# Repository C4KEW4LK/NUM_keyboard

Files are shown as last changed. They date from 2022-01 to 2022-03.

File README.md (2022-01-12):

# NUM_keyboard
Custom numpad to match CTRL keyboard

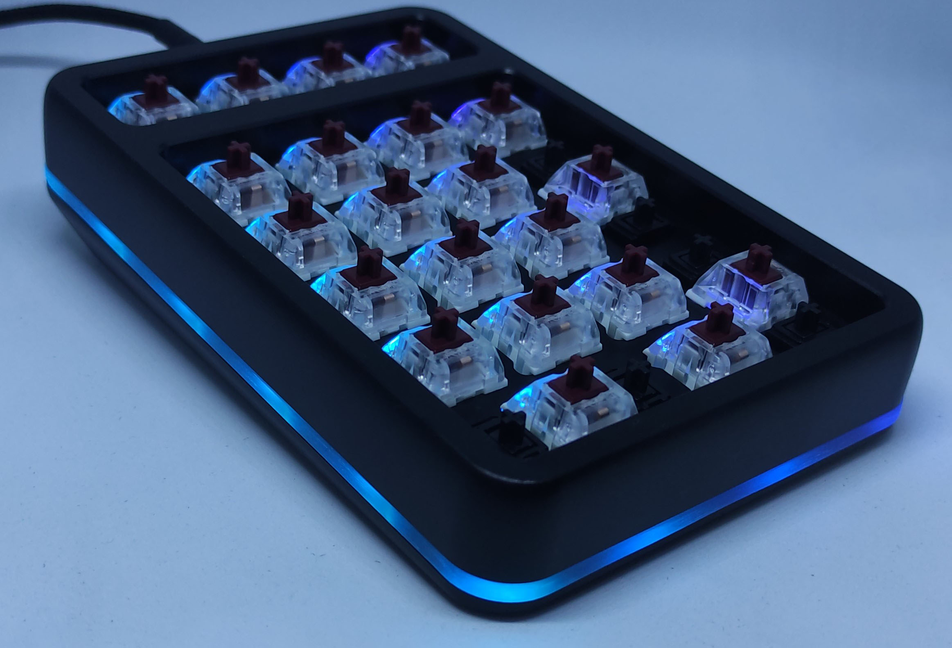
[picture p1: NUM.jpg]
Finished NUM keyboard


Version 2 fixes a couple issues with V1 but has not been fabricated, both PCB and case, so good luck.

0.2mm tolerance between pieces

Licensed: CC BY-NC-SA 4.0

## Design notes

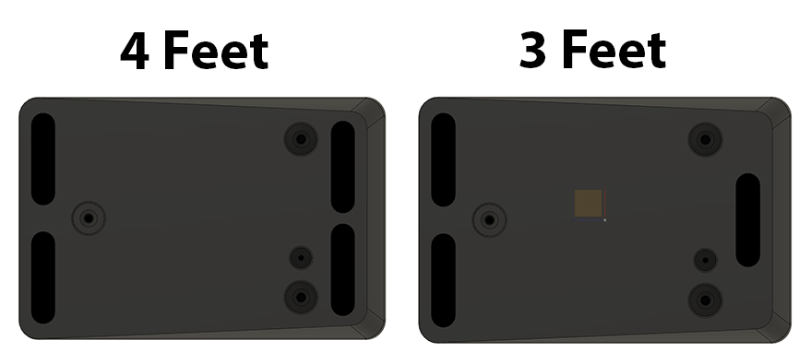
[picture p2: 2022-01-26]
CAD/V2 BOTTOM_3_vs_4_feet.png

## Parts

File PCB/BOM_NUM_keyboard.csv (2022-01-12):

ID | Name | Designator | Footprint | Quantity | Manufacturer Part | Manufacturer | Supplier | Supplier Part | link
1 | BAS321,115 | D1,D2,D3,D4,D5,D6,D7,D8,D9,D10,D11,D12,D13,D14,D15,D16,D17,D18,D19,D20,D21 | SOD-323_L1.8-W1.3-LS2.5-RD | 21 | BAS321,115 | Nexperia | LCSC | C24372 | https://lcsc.com/product-detail/Diodes-General-Purpose_Nexperia-BAS321-115_C24372.html
2 | 22pF | C23,C24 | 603 | 2 | CC0603JRNPO9BN220 | YAGEO | LCSC | C105620 | https://lcsc.com/product-detail/Multilayer-Ceramic-Capacitors-MLCC-SMD-SMT_YAGEO-CC0603JRNPO9BN220_C105620.html
3 | 1uF | C42,C25 | 603 | 2 | CC0603ZRY5V6BB105 | YAGEO | LCSC | C106220 | https://lcsc.com/product-detail/Multilayer-Ceramic-Capacitors-MLCC-SMD-SMT_YAGEO-CC0603ZRY5V6BB105_C106220.html
4 | 5.1K | R5,R3,R4 | 603 | 3 | RMC06035.1K1%N | Tyohm | LCSC | C269716 | https://lcsc.com/product-detail/Chip-Resistor-Surface-Mount_TyoHM-RMC06035-1K1-N_C269716.html
5 | 100nF | C26,C27,C28,C29,C30,C31,C32,C33,C34,C35,C36,C37,C38,C39,C40,C41,C1,C2,C3,C4,C5,C6,C7,C8,C9,C10,C11,C12,C13,C14,C15,C16,C17,C18,C19,C20,C21,C22,C43,C44,C45 | 603 | 41 | C0603B104K500NT | 火炬 | LCSC | C478888 | https://lcsc.com/product-detail/Multilayer-Ceramic-Capacitors-MLCC-SMD-SMT_TORCH-C0603B104K500NT_C478888.html
6 | 470R | R2,R1 | 603 | 2 | AECR0603F470RK9 | Resistor.Today | LCSC | C328361 | https://lcsc.com/product-detail/Chip-Resistor-Surface-Mount_Resistor-Today-AECR0603F470RK9_C328361.html
7 | 22R | R6,R7 | 603 | 2 | ERJ3RED22R0V | PANASONIC | LCSC | C416750 | https://lcsc.com/product-detail/Chip-Resistor-Surface-Mount_PANASONIC-ERJ3RED22R0V_C416750.html
8 | BTC-TC16-29 | USB1 | USB-C-SMD_BTC-TC16-29 | 1 | BTC-TC16-29 | DGBZ(东莞博众) | LCSC | C2908203 | https://lcsc.com/product-detail/USB-Connectors_DGBZ-BTC-TC16-29_C2908203.html
9 | SK6812MINI-E equivalent | U1,U2,U3,U4,U5,U6,U7,U8,U9,U10,U11,U12,U13,U14,U15,U17,U18,U19,U20,U21,U42 | CHERRYMX_1U_SK6812_MINI_3535_CW | 21 | DY-S352818/RGBC/6812-2T | TONYU | LCSC | C524051 | https://lcsc.com/product-detail/Light-Emitting-Diodes-LED_TONYU-DY-S352818-RGBC-6812-2T_C524051.html
10 | GT-TC084A-H015-L5 | SW2 | SW-SMD_4P-L5.2-W5.2-P3.70-LS6.4 | 1 | GT-TC084A-H015-L5 | G-Switch | LCSC | C778172 | https://lcsc.com/product-detail/Tactile-Switches_G-Switch-GT-TC084A-H015-L5_C778172.html
11 | 16MHz | X2 | OSC-SMD_4P-L3.2-W2.5-BL | 1 | SMD-3225_4P16M12pf10ppm | TAE | LCSC | C133336 | https://lcsc.com/product-detail/Crystals_TAE-Zhejiang-Abel-Elec-TAXM16M4RFBCCT2T_C133336.html
12 | Cherry MX hotswap sockets | U1,U2,U3,U4,U5,U6,U7,U8,U9,U10,U11,U12,U13,U14,U15,U17,U18,U19,U20,U21,U42 | CHERRYMX_1U_SK6812_MINI_3535_CW | 21 | ??? | Kailh | Aliexpress |  | https://www.aliexpress.com/item/1005003166749340.html
13 | 35x8x3 Rubber feet | ??? | ??? | 3 | ??? |  | Aliexpress |  | https://www.aliexpress.com/item/1005002019084238.html?spm=a2g0o.9042311.0.0.27424c4dmR5VNT
Choose one of the following controllers
14 | ATMEGA32U4-MUR | U24 | VQFN-44_L7.0-W7.0-P0.50-BL-EP5.2 | 1 | ATMEGA32U4-MUR | MICROCHIP | LCSC | C45874 | https://lcsc.com/product-detail/ATMEL-AVR_Microchip-Tech-ATMEGA32U4-MUR_C45874.html
14 | ATMEGA32U4-AU | U24 | QFP-44_10x10x08P | 1 | ATMEGA32U4-Au | MICROCHIP | LCSC | C44854 | https://lcsc.com/product-detail/ATMEL-AVR_Microchip-Tech-ATMEGA32U4-AU_C44854.html
Choose one of the following styles of leds
15 | SK6812MINI-ER | LED1,LED2,LED3,LED4,LED5,LED6,LED7,LED8,LED9,LED10,LED11,LED12,LED13,LED14,LED15,LED16 | LED-SMD_4P-L3.5-W2.8-BR-1 | 16 | SK6812MINI-ER | OPSCO Optoelectronics | LCSC | C2890038 | https://lcsc.com/product-detail/Light-Emitting-Diodes-LED_OPSCO-Optoelectronics-SK6812MINI-ER_C2890038.html
15 | SK6812-SIDE-A-4020 | U22,U26,U27,U28,U29,U30,U31,U32,U33,U34,U35,U36,U37,U38,U39,U40 | SK6812-SIDE-A-4020 | 16 | SK6812-Side-ARGB | OPSCO Optoelectronics | LCSC | C2890037 | https://lcsc.com/product-detail/Light-Emitting-Diodes-LED_OPSCO-Optoelectronics-SK6812SIDE-A-RVS_C2890037.html

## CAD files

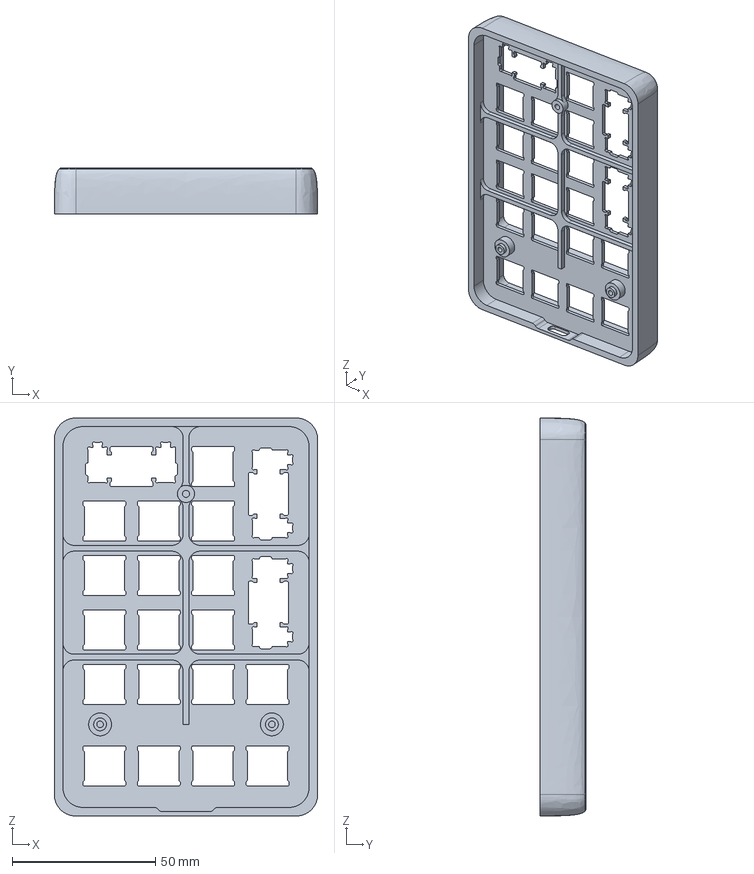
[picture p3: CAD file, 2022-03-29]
CAD/V2 TOP.step
92.0 x 16.0 x 139.0 mm

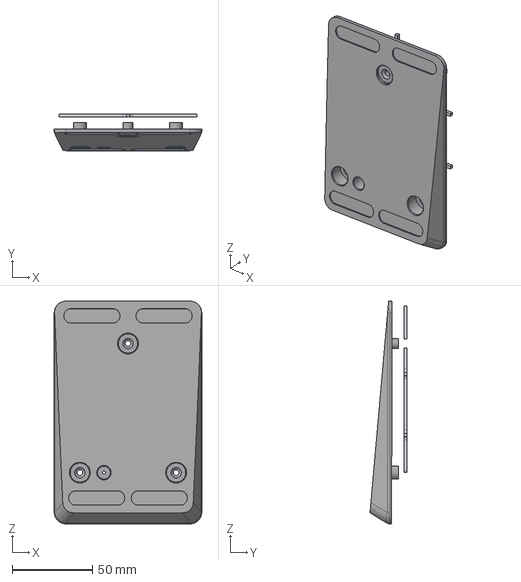
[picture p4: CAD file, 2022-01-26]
CAD/V2 BOTTOM_4_feet.step
92.0 x 23.1 x 139.0 mm

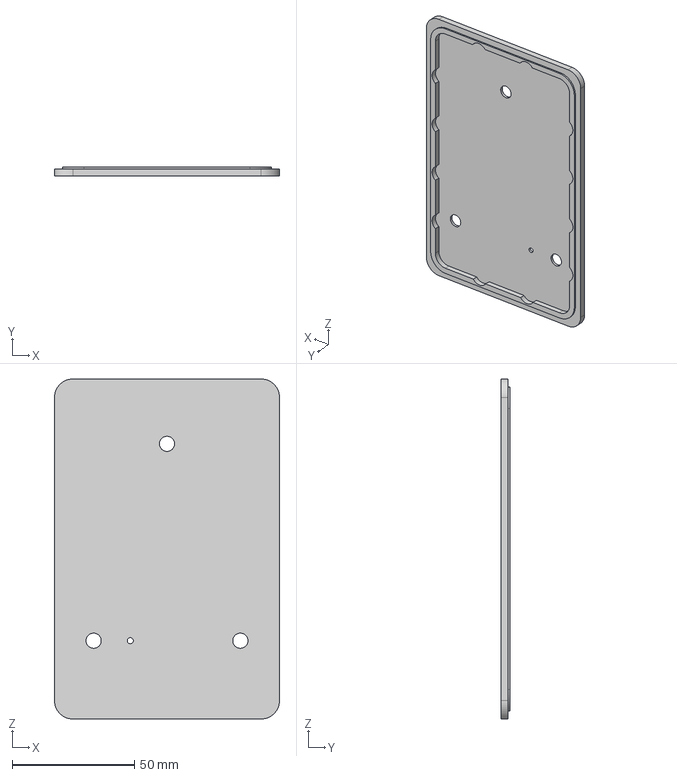
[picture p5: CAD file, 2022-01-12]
CAD/V2 Acrylic.step
92.0 x 3.80 x 139.0 mm

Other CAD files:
CAD/V2 BOTTOM_3_feet.step

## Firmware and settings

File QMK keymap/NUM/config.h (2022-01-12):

/*
Copyright 2020

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
You should have received a copy of the GNU General Public License
along with this program.  If not, see <http://www.gnu.org/licenses/>.
*/

#pragma once

#include "config_common.h"

/* USB Device descriptor parameter */
#define VENDOR_ID 0x4357  // "CW"
#define PRODUCT_ID 0x4E4D
#define DEVICE_VER 0x0001
#define MANUFACTURER Cakewalk
#define PRODUCT NUM

/* key matrix size */
#define MATRIX_ROWS 6
#define MATRIX_COLS 4

/*
 * Keyboard Matrix Assignments
 *
 * Change this to how you wired your keyboard
 * COLS: AVR pins used for columns, left to right
 * ROWS: AVR pins used for rows, top to bottom
 * DIODE_DIRECTION: COL2ROW = COL = Anode (+), ROW = Cathode (-, marked on diode)
 *                  ROW2COL = ROW = Anode (+), COL = Cathode (-, marked on diode)
 *
 */
#define MATRIX_ROW_PINS \
    { D0, D1, D2, D3, D4, D5 }
#define MATRIX_COL_PINS \
    { B4, B5, B6, C6 }
#define UNUSED_PINS

/* COL2ROW, ROW2COL */
#define DIODE_DIRECTION COL2ROW

/*
 * Split Keyboard specific options, make sure you have 'SPLIT_KEYBOARD = yes' in your rules.mk, and define SOFT_SERIAL_PIN.
 */
#define SOFT_SERIAL_PIN D0  // or D1, D2, D3, E6

#define RGB_DI_PIN F6
#define RGBLED_NUM 37
#define DRIVER_LED_TOTAL RGBLED_NUM

#define RGB_MATRIX_MAXIMUM_BRIGHTNESS 150  // limits maximum brightness of LEDs to 150 out of 255. Higher may cause the controller to crash.
#define RGB_MATRIX_KEYPRESSES
#define RGB_MATRIX_FRAMEBUFFER_EFFECTS
#define RGB_MATRIX_HUE_STEP 8
#define RGB_MATRIX_SAT_STEP 8
#define RGB_MATRIX_VAL_STEP 8
#define RGB_MATRIX_SPD_STEP 10

//#define RGBLIGHT_SLEEP  /* If defined, the RGB lighting will be switched off when the host goes to sleep */
// /*== all animations enable ==*/
//    #define RGBLIGHT_ANIMATIONS
// /*== or choose animations ==*/
//   #define RGBLIGHT_EFFECT_BREATHING
//   #define RGBLIGHT_EFFECT_RAINBOW_MOOD
//   #define RGBLIGHT_EFFECT_RAINBOW_SWIRL
//   #define RGBLIGHT_EFFECT_SNAKE
//   #define RGBLIGHT_EFFECT_KNIGHT
//   #define RGBLIGHT_EFFECT_CHRISTMAS
//   #define RGBLIGHT_EFFECT_STATIC_GRADIENT
//   #define RGBLIGHT_EFFECT_RGB_TEST
//   #define RGBLIGHT_EFFECT_ALTERNATING
// /*== customize breathing effect ==*/
//   /*==== (DEFAULT) use fixed table instead of exp() and sin() ====*/
//   #define RGBLIGHT_BREATHE_TABLE_SIZE 256      // 256(default) or 128 or 64
//   /*==== use exp() and sin() ====*/
//   #define RGBLIGHT_EFFECT_BREATHE_CENTER 1.85  // 1 to 2.7
//   #define RGBLIGHT_EFFECT_BREATHE_MAX    255   // 0 to 255

/* Debounce reduces chatter (unintended double-presses) - set 0 if debouncing is not needed */
#define DEBOUNCE 5

/* define if matrix has ghost (lacks anti-ghosting diodes) */
//#define MATRIX_HAS_GHOST

/* Mechanical locking support. Use KC_LCAP, KC_LNUM or KC_LSCR instead in keymap */
#define LOCKING_SUPPORT_ENABLE
/* Locking resynchronize hack */
#define LOCKING_RESYNC_ENABLE

/* If defined, GRAVE_ESC will always act as ESC when CTRL is held.
 * This is userful for the Windows task manager shortcut (ctrl+shift+esc).
 */
// #define GRAVE_ESC_CTRL_OVERRIDE

/*
 * Force NKRO
 *
 * Force NKRO (nKey Rollover) to be enabled by default, regardless of the saved
 * state in the bootmagic EEPROM settings. (Note that NKRO must be enabled in the
 * makefile for this to work.)
 *
 * If forced on, NKRO can be disabled via magic key (default = LShift+RShift+N)
 * until the next keyboard reset.
 *
 * NKRO may prevent your keystrokes from being detected in the BIOS, but it is
 * fully operational during normal computer usage.
 *
 * For a less heavy-handed approach, enable NKRO via magic key (LShift+RShift+N)
 * or via bootmagic (hold SPACE+N while plugging in the keyboard). Once set by
 * bootmagic, NKRO mode will always be enabled until it is toggled again during a
 * power-up.
 *
 */
//#define FORCE_NKRO

/*
 * Feature disable options
 *  These options are also useful to firmware size reduction.
 */

/* disable debug print */
//#define NO_DEBUG

/* disable print */
//#define NO_PRINT

/* disable action features */
//#define NO_ACTION_LAYER
//#define NO_ACTION_TAPPING
//#define NO_ACTION_ONESHOT

/* disable these deprecated features by default */
#define NO_ACTION_MACRO
#define NO_ACTION_FUNCTION

/* Bootmagic Lite key configuration */
// #define BOOTMAGIC_LITE_ROW 0
// #define BOOTMAGIC_LITE_COLUMN 0


#define RGBLIGHT_SLEEP

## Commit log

2022-01-12 Init commit
    Init commit
    [Gerber_BoardOutline.GKO, Gerber_BottomLayer.GBL, Gerber_BottomPasteMaskLayer.GBP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]
2022-01-12 changed ext
    [BOM_NUM_keyboard.csv]
2022-01-12 changed diode positions
    [Gerber_BoardOutline.GKO, Gerber_BottomLayer.GBL, Gerber_BottomPasteMaskLayer.GBP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]
2022-01-26 add 4 feet option
    added 4 feet option
    [V2 BOTTOM_3_feet.step, V2 BOTTOM_4_feet.step]
2022-03-29 Update V2 TOP.step
    issue with file
    [V2 TOP.step]

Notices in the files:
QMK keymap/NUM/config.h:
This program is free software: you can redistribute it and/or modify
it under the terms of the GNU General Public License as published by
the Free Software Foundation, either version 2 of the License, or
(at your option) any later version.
